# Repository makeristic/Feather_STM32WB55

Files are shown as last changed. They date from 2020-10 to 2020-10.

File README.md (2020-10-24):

# Feather STM32WB55

## WARNING: Work In Progress

This is a work in progress, it may not work at all.  :)

## Overview

I have several [Adafruit Feather](https://www.adafruit.com/category/943) boards, and Adafruit handily publish the [Feather Specification](https://learn.adafruit.com/adafruit-feather/feather-specification) here to make your own.  

I recently discovered the STM32WB series of microcontrollers which include Bluetooth connectivity and decided to build my own development board around it.  This repository is my first attempt at designing it and builds upon the great work of several sources (see Acknowledgements below).

The ultimate goal is to get this board working and running [CircuitPython](https://circuitpython.org/), once working I may do another revision with a focus on enabling more of the low power features of the STM32WB series.

## Features

* [STM32WB55CGU6](https://www.st.com/en/microcontrollers-microprocessors/stm32wb55cg.html) microcontroller
* Adafruit Feather compatible, with USB-C
* (Optional) QSPI-Dual flash module can be soldered to the back
* (Optional) ARM SWD 10-pin debug connector can be soldered on the back

## Notes

* 4-layer board, 1mm thick with impedence controlled traces, and assumes the standard JLCPCB stackup.
* I've tried to standardise on 0.2mm tracks for signals, 0.3mm tracks for power.  VBUS and +BATT do have high-current tracks/pours to their respective pins to allow for powering things off-board like Neopixels.
* STMicroelectronics produce a custom matching network for this microcontroller [MLPF-WB55-01E3](https://www.st.com/en/emi-filtering-and-signal-conditioning/mlpf-wb55-01e3.html), the recommended PCB layout has been implemented here.
* The [Fractus Antenna](https://fractusantennas.com/compact-reach-xtend-nn01-102/) has a recommended layout which is implemented here.  The clearance area essentially takes up the entire tip of the board, though I have cheekily added the STEMMA QT connector, figuring it shouldn't have too big an impact.
* There is a lot of space around the center of the board, this is semi-intentional so I can extend the design with sensors, or an additional button.
* You can find my custom footprints etc. here [Makeristic-KiCad-Library](https://github.com/makeristic/Makeristic-KiCad-Library)

## Schematic

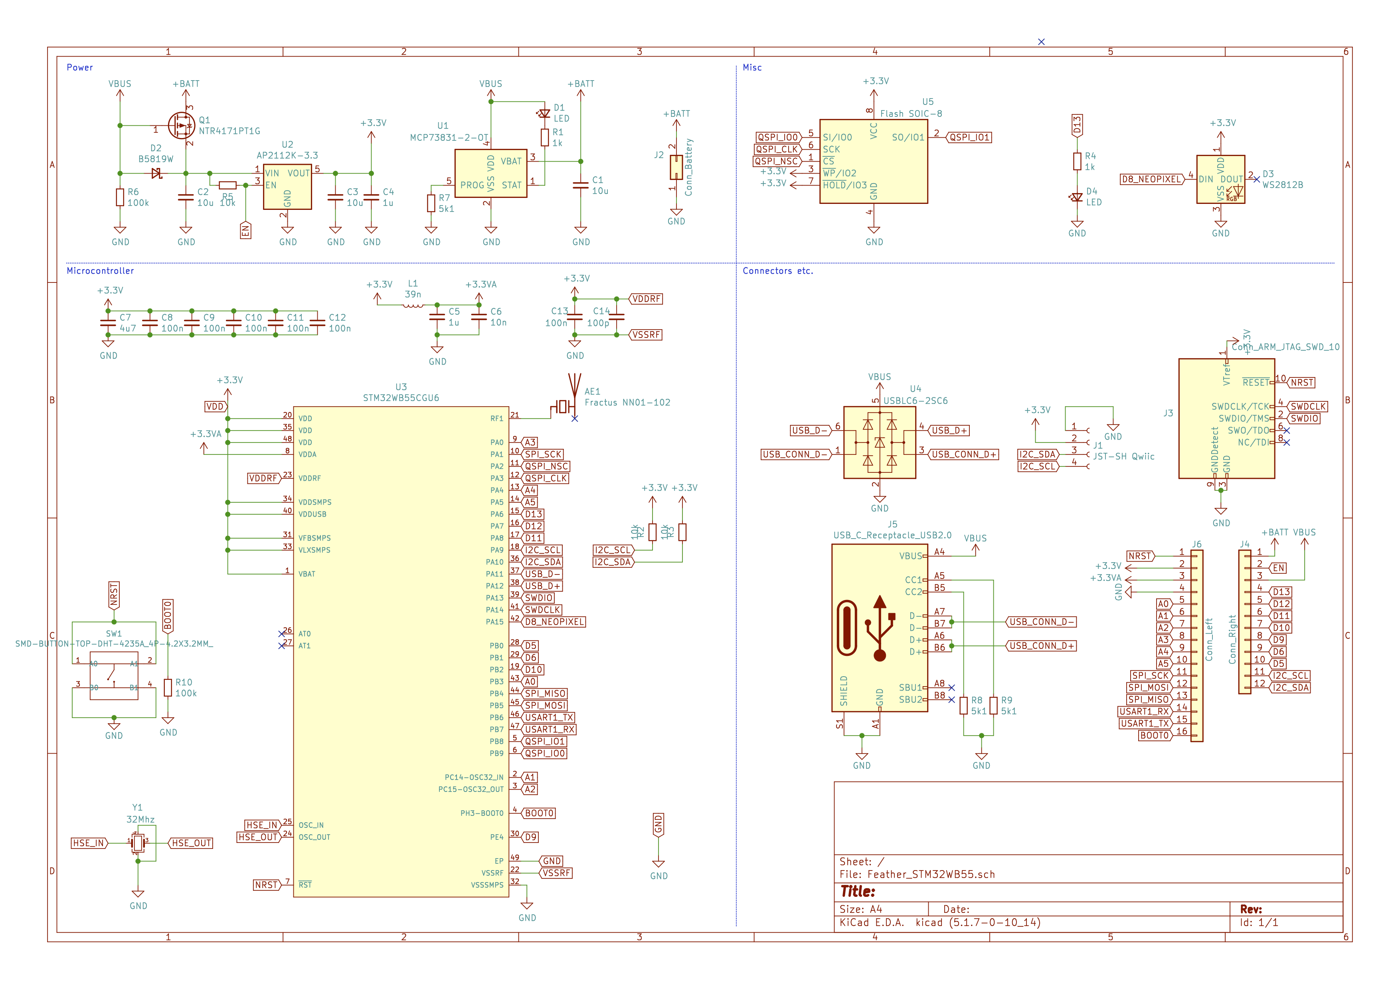
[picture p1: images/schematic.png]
Schematic


## PCB

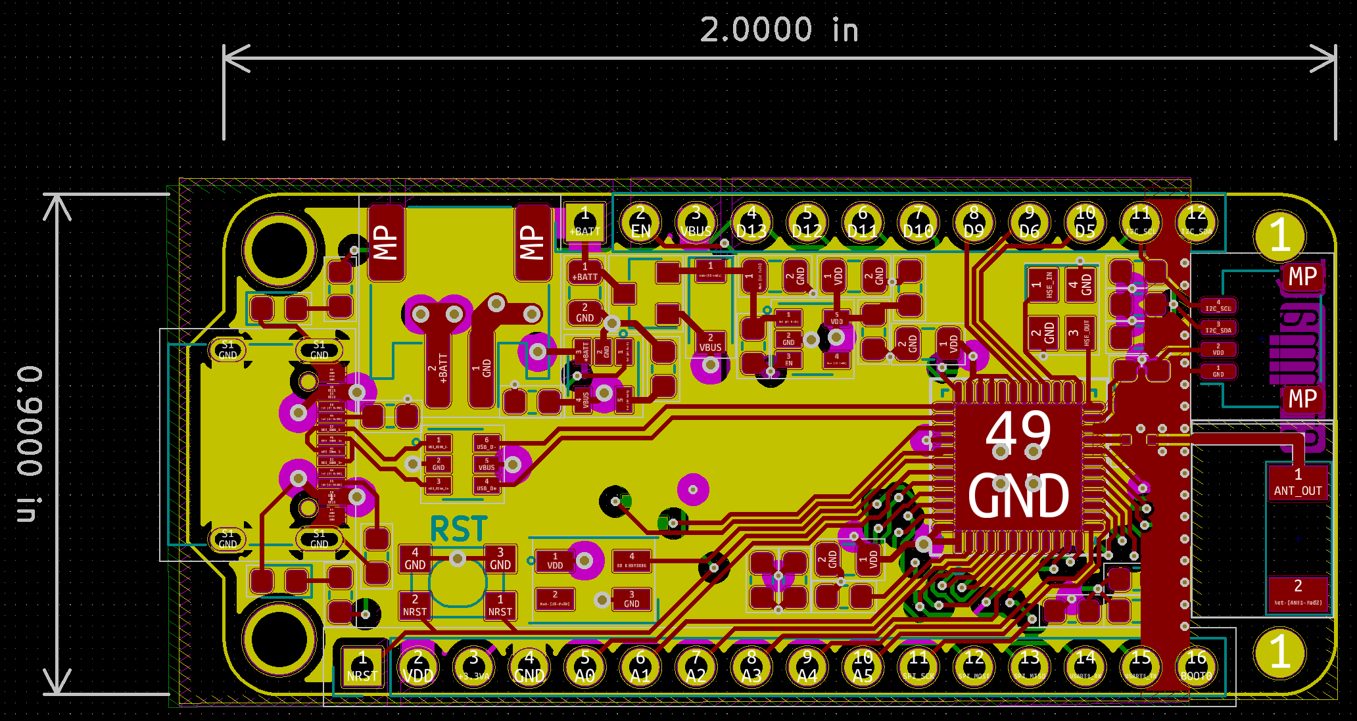
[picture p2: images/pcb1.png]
PCB with inner layers


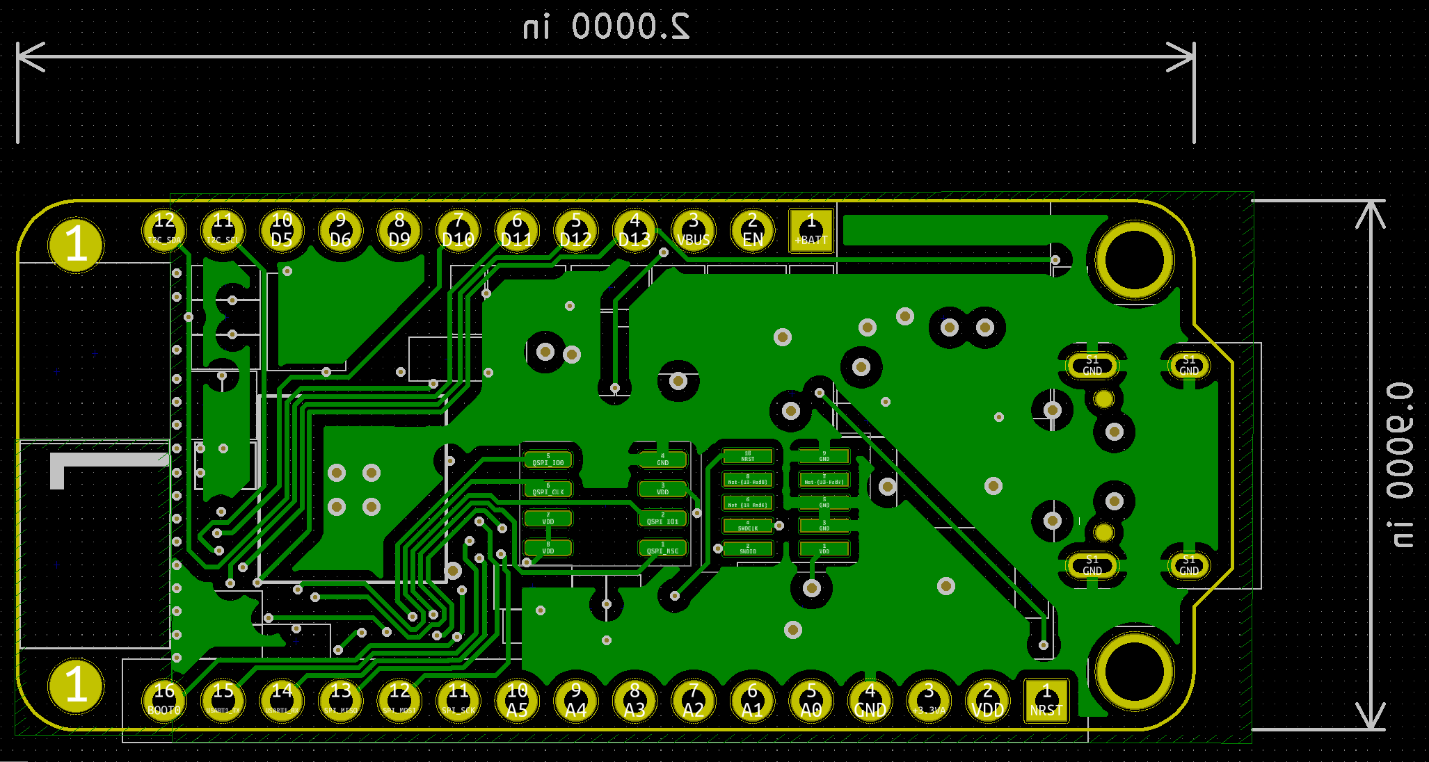
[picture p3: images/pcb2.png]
PCB without inner layers


## 3D Render

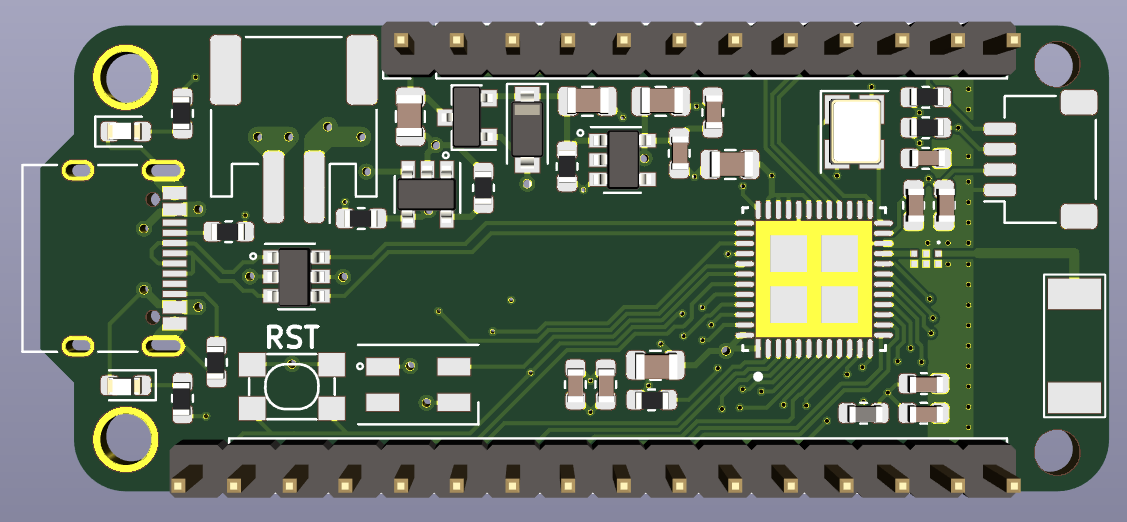
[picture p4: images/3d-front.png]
3D Front


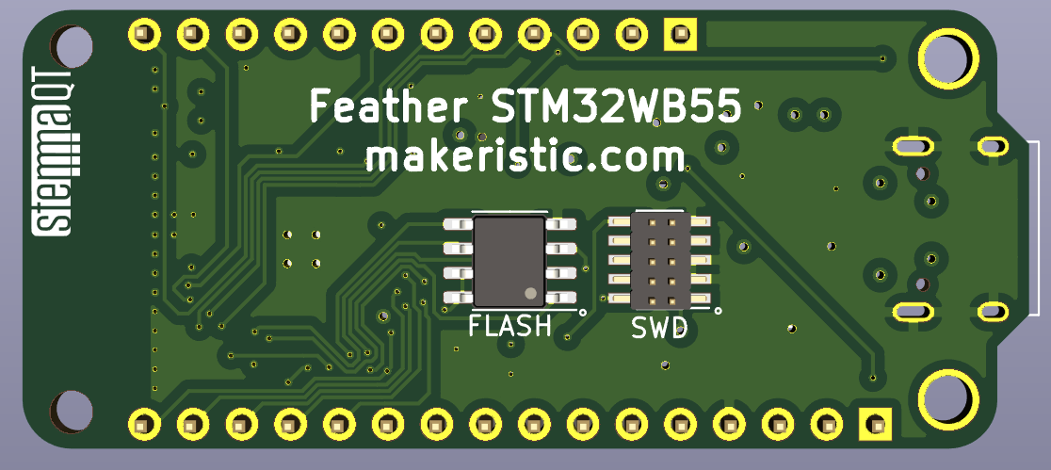
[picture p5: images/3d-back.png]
3D Back


## TODO

* Improve the layout, potentially reassigning GPIO pins to simplify the traces

## Acknowledgements

* [Adafruit](https://www.adafruit.com/)
* [YouTube: Phil's Lab](https://www.youtube.com/c/PhilS94/videos)

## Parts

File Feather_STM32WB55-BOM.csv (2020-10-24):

Reference | Value | Footprint | Datasheet | LCSC Part # | Manufacturer Part # | RAM size | ambient temperature range high | ambient temperature range low | automotive | category | core architecture | data bus width | device class L1 | device class L2 | device class L3 | digikey description | digikey part number | frequency | height | interface | lead free | library id | manufacturer | max junction temp | max supply voltage | memory size | memory type | min supply voltage | mouser part number | number of A/D converters | number of ADC channels | number of I/Os | number of I2C channels | number of PWM channels | number of SPI channels | number of UART channels | number of USB channels | number of cores | number of timers/counters | package | rohs | standoff height | temperature range high | temperature range low | MPN | SKU | Description | Height | Manufacturer_Name | Manufacturer_Part_Number | Mouser Part Number | Mouser Price/Stock | Arrow Part Number | Arrow Price/Stock
J4 | Conn_Right | Connector_PinHeader_2.54mm:PinHeader_1x12_P2.54mm_Vertical | ~
J6 | Conn_Left | Connector_PinHeader_2.54mm:PinHeader_1x16_P2.54mm_Vertical | ~
J2 | Conn_Battery | Connector_JST:JST_PH_S2B-PH-SM4-TB_1x02-1MP_P2.00mm_Horizontal | https://datasheet.lcsc.com/szlcsc/2004071131_JST-Sales-America-S2B-PH-SM4-TB-LF-SN_C295747.pdf | C295747 | S2B-PH-SM4-TB(LF)(SN)
J5 | USB_C_Receptacle_USB2.0 | Connector_USB:USB_C_Receptacle_XKB_U262-16XN-4BVC11 | https://datasheet.lcsc.com/szlcsc/2002271811_XKB-Enterprise-U262-161N-4BVC11_C319148.pdf | C319148 | U262-161N-4BVC11
U3 | STM32WB55CGU6 | IC_STMicroelectronics_STM32WB55CGU6:STMicroelectronics-STM32WB55CGU6-IPC_B | https://www.st.com/resource/en/datasheet/stm32wb55cg.pdf |  |  | 256KBytes | +85°C | -40°C | No | IC | ARM Cortex-M4 | 32bits | Integrated Circuits (ICs) | Embedded Processors and Controllers | Microcontrollers | ULTRA-LOW-POWER DUAL CORE ARM CO | 497-18489-ND | 64MHz | 0.65mm | I2C,SPI,UART,USART,2-Wire,USB,IrDA,Other | Yes | 7cd8443577175ffa | STMicroelectronics | +105°C | 3.6V | 1MBytes | FLASH | 1.71V | 511-STM32WB55CGU6 | 1 | 13 | 30 | 2 | 14 | 1 | 2 | 1 | 1 | 6 | UFQFPN48 | Yes | 0mm | +105°C | -40°C
J3 | Conn_ARM_JTAG_SWD_10 | Connector_PinHeader_1.00mm:PinHeader_2x05_P1.00mm_Vertical_SMD | http://infocenter.arm.com/help/topic/com.arm.doc.ddi0314h/DDI0314H_coresight_components_trm.pdf
U4 | USBLC6-2SC6 | Package_TO_SOT_SMD:SOT-23-6 | https://www.st.com/resource/en/datasheet/usblc6-2.pdf
C13 | 100n | Capacitor_SMD:C_0603_1608Metric | ~
Y1 | 32Mhz | Crystal:Crystal_SMD_3225-4Pin_3.2x2.5mm | https://datasheet.lcsc.com/szlcsc/Seiko-Epson-X1E0000210163000G_C91742.pdf | C91742 | X1E000021016300
L1 | 39n | Inductor_SMD:L_0603_1608Metric | ~
C5 | 1u | Capacitor_SMD:C_0603_1608Metric | ~
C6 | 10n | Capacitor_SMD:C_0603_1608Metric | ~
C7 | 4u7 | Capacitor_SMD:C_0805_2012Metric | ~
C8 | 100n | Capacitor_SMD:C_0603_1608Metric | ~
C9 | 100n | Capacitor_SMD:C_0603_1608Metric | ~
C10 | 100n | Capacitor_SMD:C_0603_1608Metric | ~
C11 | 100n | Capacitor_SMD:C_0603_1608Metric | ~
C12 | 100n | Capacitor_SMD:C_0603_1608Metric | ~
C14 | 100p | Capacitor_SMD:C_0603_1608Metric | ~
U2 | AP2112K-3.3 | Package_TO_SOT_SMD:SOT-23-5 | https://www.diodes.com/assets/Datasheets/AP2112.pdf
R5 | 10k | Resistor_SMD:R_0603_1608Metric | ~
Q1 | NTR4171PT1G | Package_TO_SOT_SMD:SOT-23 | https://datasheet.lcsc.com/szlcsc/2005221838_VBsemi-Elec-NTR4171PT1G_C558218.pdf | C558218 | NTR4171PT1G
C2 | 10u | Capacitor_SMD:C_0805_2012Metric | ~
C3 | 10u | Capacitor_SMD:C_0805_2012Metric | ~
C4 | 1u | Capacitor_SMD:C_0805_2012Metric | ~
U1 | MCP73831-2-OT | Package_TO_SOT_SMD:SOT-23-5 | http://ww1.microchip.com/downloads/en/DeviceDoc/20001984g.pdf
C1 | 10u | Capacitor_SMD:C_0805_2012Metric | ~
R7 | 5k1 | Resistor_SMD:R_0603_1608Metric | ~
R1 | 1k | Resistor_SMD:R_0603_1608Metric | ~
D1 | LED | LED_SMD:LED_0603_1608Metric | ~
R8 | 5k1 | Resistor_SMD:R_0603_1608Metric | ~
R9 | 5k1 | Resistor_SMD:R_0603_1608Metric | ~
D3 | WS2812B | LED_SMD:LED_SK6812MINI_PLCC4_3.5x3.5mm_P1.75mm | https://cdn-shop.adafruit.com/datasheets/WS2812B.pdf
R4 | 1k | Resistor_SMD:R_0603_1608Metric | ~
D4 | LED | LED_SMD:LED_0603_1608Metric | ~
J1 | JST-SH Qwiic | Connector_JST:JST_SH_SM04B-SRSS-TB_1x04-1MP_P1.00mm_Horizontal | ~
R2 | 10k | Resistor_SMD:R_0603_1608Metric | ~
R3 | 10k | Resistor_SMD:R_0603_1608Metric | ~
R10 | 100k | Resistor_SMD:R_0603_1608Metric | ~
U5 | Flash SOIC-8 | Package_SO:SOIC-8_3.9x4.9mm_P1.27mm | https://www.adestotech.com/wp-content/uploads/DS-AT25SF081_045.pdf
D2 | B5819W | Diode_SMD:D_SOD-123 | https://datasheet.lcsc.com/szlcsc/1809140216_Changjiang-Electronics-Tech-CJ-B5819W_C8598.pdf | C8598
R6 | 100k | Resistor_SMD:R_0603_1608Metric | ~
SW1 | SMD-BUTTON-TOP-DHT-4235A_4P-4.2X3.2MM_ | OPL_Switch:SW4-SMD-4.2X3.2X2.5MM |  |  |  |  |  |  |  |  |  |  |  |  |  |  |  |  |  |  |  |  |  |  |  |  |  |  |  |  |  |  |  |  |  |  |  |  |  |  |  |  |  |  | DHT-4235A | 311020045
ANT1 | NN01-102 | FR05S1N0102 | https://www.fractusantennas.com/files/UM_FR05_S1_N_0_102.pdf |  |  |  |  |  |  |  |  |  |  |  |  |  |  |  |  |  |  |  |  |  |  |  |  |  |  |  |  |  |  |  |  |  |  |  |  |  |  |  |  |  |  |  | Compact Reach XtendTM (FR05-S1-N-0-102) Bluetooth, Zigbee, 802.11 b/g/n WLAN | 2.2 | Fractus Antennas | FR05-S1-N-0-102 | 128-FR05-S1-N-0-102 | https://www.mouser.co.uk/ProductDetail/Fractus-Antennas/FR05-S1-N-0-102?qs=OTrKUuiFdkYH9yRdQjVA9Q%3D%3D
FL1 | MLPF-WB55-01E3 | MLPFWB5501E3 | https://www.st.com/resource/en/datasheet/mlpf-wb55-01e3.pdf |  |  |  |  |  |  |  |  |  |  |  |  |  |  |  |  |  |  |  |  |  |  |  |  |  |  |  |  |  |  |  |  |  |  |  |  |  |  |  |  |  |  |  | RF Wireless Misc 2.4 GHz Low Pass Filter matched to STM32WB55 | 0.7 | STMicroelectronics | MLPF-WB55-01E3 | 511-MLPF-WB55-01E3 | https://www.mouser.co.uk/ProductDetail/STMicroelectronics/MLPF-WB55-01E3?qs=vLWxofP3U2xV%2FkxL9PmCDA%3D%3D | MLPF-WB55-01E3 | https://www.arrow.com/en/products/mlpf-wb55-01e3/stmicroelectronics

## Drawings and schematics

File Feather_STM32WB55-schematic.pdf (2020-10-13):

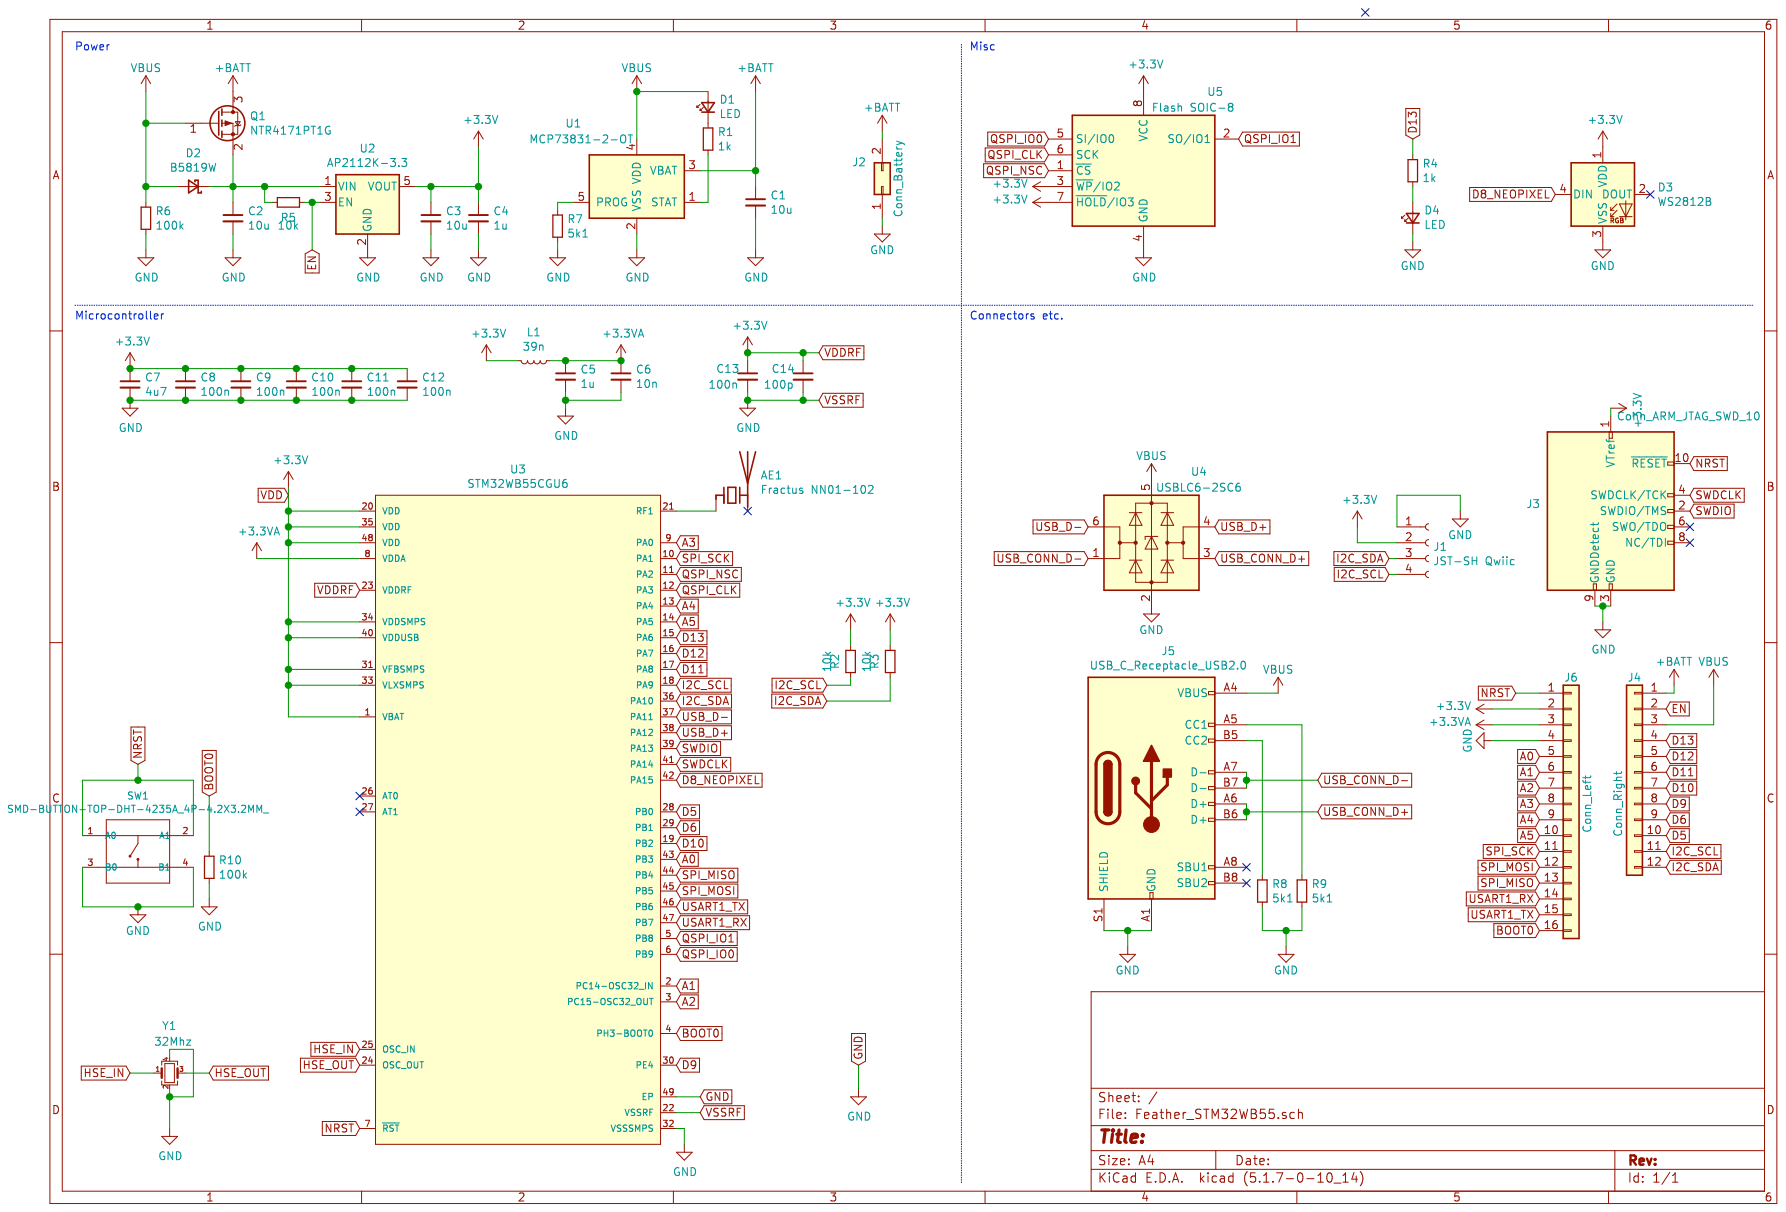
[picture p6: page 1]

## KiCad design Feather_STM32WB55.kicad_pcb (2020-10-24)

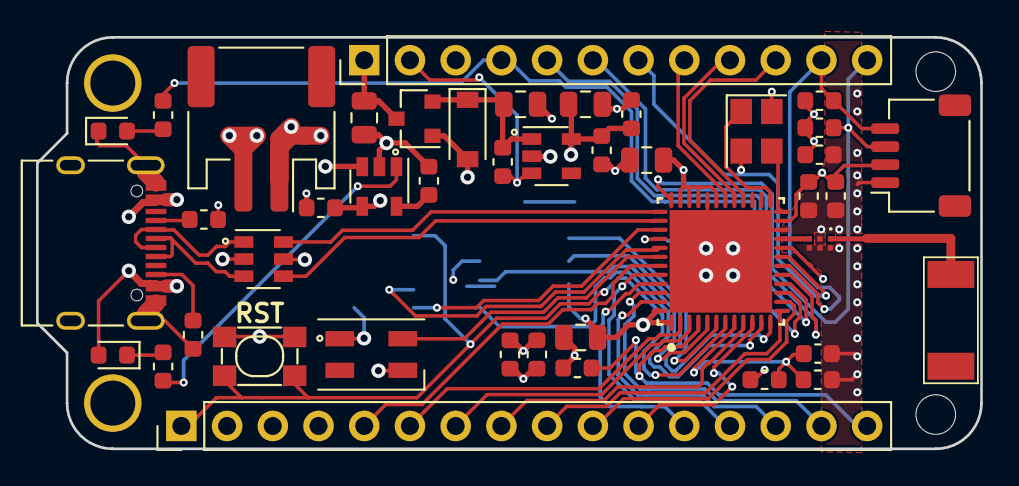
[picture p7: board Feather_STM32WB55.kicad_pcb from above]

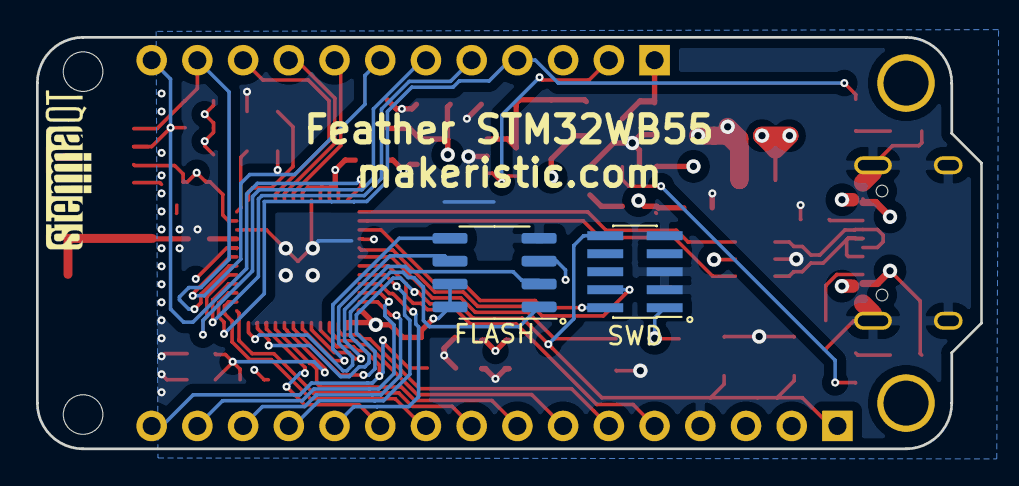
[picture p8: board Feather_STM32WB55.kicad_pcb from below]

Board: 4 copper layers, 52.5 x 22.9 mm, 45 parts (2 on the bottom side), 50 nets.

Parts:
ANT1: NN01-102; FR05S1N0102
C1, C2, C3: 10u; C_0805_2012Metric
C4: 1u; C_0805_2012Metric
C5: 1u; C_0603_1608Metric
C6: 10n; C_0603_1608Metric
C7: 4u7; C_0805_2012Metric
C8, C9, C10, C11, C12, C13: 100n; C_0603_1608Metric
C14: 100p; C_0603_1608Metric
D1, D4: LED; LED_0603_1608Metric
D2: B5819W; D_SOD-123
D3: WS2812B; LED_SK6812MINI_PLCC4_3.5x3.5mm_P1.75mm
FL1: MLPF-WB55-01E3; MLPFWB5501E3
FLASH: Flash SOIC-8; SOIC-8_3.9x4.9mm_P1.27mm
J1: JST-SH Qwiic; JST_SH_SM04B-SRSS-TB_1x04-1MP_P1.00mm_Horizontal
J2: Conn_Battery; JST_PH_S2B-PH-SM4-TB_1x02-1MP_P2.00mm_Horizontal
J4: Conn_Right; PinHeader_1x12_P2.54mm_Vertical
J5: USB_C_Receptacle_USB2.0; USB_C_Receptacle_XKB_U262-16XN-4BVC11
J6: Conn_Left; PinHeader_1x16_P2.54mm_Vertical
L1: 39n; L_0603_1608Metric
Q1: NTR4171PT1G; SOT-23
R1, R4: 1k; R_0603_1608Metric
R2, R3, R5: 10k; R_0603_1608Metric
R6, R10: 100k; R_0603_1608Metric
R7, R8, R9: 5k1; R_0603_1608Metric
SW1: SMD-BUTTON-TOP-DHT-4235A_4P-4.2X3.2MM_; SW4-SMD-4.2X3.2X2.5MM
SWD: Conn_ARM_JTAG_SWD_10; PinHeader_2x05_P1.00mm_Vertical_SMD
U1: MCP73831-2-OT; SOT-23-5
U2: AP2112K-3.3; SOT-23-5
U3: STM32WB55CGU6; STMicroelectronics-STM32WB55CGU6-IPC_B
U4: USBLC6-2SC6; SOT-23-6
Y1: 32Mhz; Crystal_SMD_3225-4Pin_3.2x2.5mm

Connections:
+3.3VA: C5.1, C6.1, J6.3, L1.1, U3.8
+BATT: C1.1, J2.2, J4.1, Q1.3, U1.3
A0: J6.5, U3.43
A1: J6.6, U3.2
A2: J6.7, U3.3
A3: J6.8, U3.9
A4: J6.9, U3.13
A5: J6.10, U3.14
ANT_OUT: ANT1.1, FL1.1
BOOT0: J6.16, R10.1, U3.4
D5: J4.10, U3.28
D6: J4.9, U3.29
D8_NEOPIXEL: D3.4, U3.42
D9: J4.8, U3.30
D10: J4.7, U3.19
D11: J4.6, U3.17
D12: J4.5, U3.16
D13: J4.4, R4.1, U3.15
EN: J4.2, R5.2, U2.3
GND: C1.2, C2.2, C3.2, C4.2, C5.2, C6.2, C7.2, C8.2, C9.2, C10.2, C11.2, C12.2, C13.2, C14.2, D3.3, D4.1, FL1.2, FL1.4, FL1.5, FL1.6, FLASH.4, J1.1, J2.1, J5.A1, J5.A12, J5.B1, J5.B12, J5.S1, J6.4, R6.2, R7.2, R8.2, R9.2, R10.2, SW1.3, SW1.4, SWD.3, SWD.5, SWD.9, U1.2, U2.2, U3.22, U3.32, U3.49, U4.2, Y1.2, Y1.4
HSE_IN: U3.25, Y1.1
HSE_OUT: U3.24, Y1.3
I2C_SCL: J1.4, J4.11, R2.2, U3.18
I2C_SDA: J1.3, J4.12, R3.2, U3.36
NRST: J6.1, SW1.1, SW1.2, SWD.10, U3.7
unnamed: C2.1, D2.1, Q1.2, R5.1, U2.1
unnamed: D1.1, R1.1
unnamed: D4.2, R4.2
unnamed: J5.A5, R9.1
unnamed: J5.B5, R8.1
unnamed: R1.2, U1.1
unnamed: R7.1, U1.5
QSPI_CLK: FLASH.6, U3.12
QSPI_IO0: FLASH.5, U3.6
QSPI_IO1: FLASH.2, U3.5
QSPI_NSC: FLASH.1, U3.11
RF_OUT: FL1.3, U3.21
SPI_MISO: J6.13, U3.44
SPI_MOSI: J6.12, U3.45
SPI_SCK: J6.11, U3.10
SWDCLK: SWD.4, U3.41
SWDIO: SWD.2, U3.39
USART1_RX: J6.14, U3.47
USART1_TX: J6.15, U3.46
USB_CONN_D+: J5.A6, J5.B6, U4.3
USB_CONN_D-: J5.A7, J5.B7, U4.1
USB_D+: U3.38, U4.4
USB_D-: U3.37, U4.6
VBUS: D1.2, D2.2, J4.3, J5.A4, J5.A9, J5.B4, J5.B9, Q1.1, R6.1, U1.4, U4.5
VDD: C3.1, C4.1, C7.1, C8.1, C9.1, C10.1, C11.1, C12.1, C13.1, C14.1, D3.1, FLASH.3, FLASH.7, FLASH.8, J1.2, J6.2, L1.2, R2.1, R3.1, SWD.1, U2.5, U3.1, U3.20, U3.23, U3.31, U3.33, U3.34, U3.35, U3.40, U3.48

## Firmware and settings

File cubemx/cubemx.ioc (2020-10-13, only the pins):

Mcu.UserName=STM32WB55CGUx
PA0.Signal=GPIO_Analog
PA1.Signal=SPI1_SCK
PA10.Signal=I2C1_SDA
PA11.Signal=USB_DM
PA12.Signal=USB_DP
PA13.Signal=SYS_JTMS-SWDIO
PA14.Signal=SYS_JTCK-SWCLK
PA15.Signal=GPIO_Output
PA2.Signal=QUADSPI_BK1_NCS
PA3.Signal=QUADSPI_CLK
PA4.Signal=GPIO_Analog
PA5.Signal=GPIO_Analog
PA6.Signal=GPIO_Output
PA7.Signal=GPIO_Output
PA8.Signal=GPIO_Analog
PA9.Signal=I2C1_SCL
PB0.Signal=GPIO_Output
PB1.Signal=GPIO_Analog
PB2.Signal=GPIO_Analog
PB3.Signal=GPIO_Output
PB4.Signal=SPI1_MISO
PB5.Signal=SPI1_MOSI
PB6.Signal=USART1_TX
PB7.Signal=USART1_RX
PB8.Signal=QUADSPI_BK1_IO1
PB9.Signal=QUADSPI_BK1_IO0
PC14-OSC32_IN.Signal=GPIO_Output
PC15-OSC32_OUT.Signal=GPIO_Output
PE4.Signal=GPIO_Output
PH3-BOOT0.Signal=GPIO_Input

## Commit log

2020-10-13 Added images
    [Feather_STM32WB55.kicad_pcb]
2020-10-14 Removed copper fill on F.Cu updated the PCB images
    [Feather_STM32WB55.kicad_pcb]
2020-10-15 Updated with the matching network and antenna
    [Feather_STM32WB55.kicad_pcb, Feather_STM32WB55.sch]
2020-10-21 Updated ready for manufacturing
    [Feather_STM32WB55-B_Cu.gbr, Feather_STM32WB55-B_Mask.gbr, Feather_STM32WB55-B_Paste.gbr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]
2020-10-24 v1.1 work in progress
    [Feather_STM32WB55-BOM.csv, Feather_STM32WB55.kicad_pcb]
2020-10-24 Tidied up the power section, rearranged components, standardised traces to 0.3mm for power lines, 0.2mm for data lines
    [Feather_STM32WB55.kicad_pcb]
2020-10-24 More tidying up of traces and silkscreen
    [Feather_STM32WB55.kicad_pcb]
2020-10-24 OCD moving traces around
    [Feather_STM32WB55.kicad_pcb]
2020-10-24 Updated gerbers
    [Feather_STM32WB55-B_Cu.gbr, Feather_STM32WB55-B_Mask.gbr, Feather_STM32WB55-B_Paste.gbr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]
2026-10-26 fix: repair STM32WB55 short and restore project libraries (#1)
    * docs: improve project discovery and reuse guidance
    Describe the historical design and available artifacts from repository evidence. Keep hardware and fabrication outputs unchanged, preserve third-party rights, and make unresolved setup and validation limits visible.
    * docs: record completed discoverability delivery
    * fix: clear the D10 ground short and restore legacy libraries
    Move the overlapping ground via using a controlled before/after zone-refilled DRC comparison. Recover original dependencies and align component identifiers without redesigning the land pattern or guessing the physical stackup. Keep historical fabricat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
